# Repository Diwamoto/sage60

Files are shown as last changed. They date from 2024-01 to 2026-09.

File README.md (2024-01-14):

# Sage60

東プレスイッチを使った60%分割キーボードです。
nrf52840を使って無線接続で左右間接続、PCとの接続を行います。
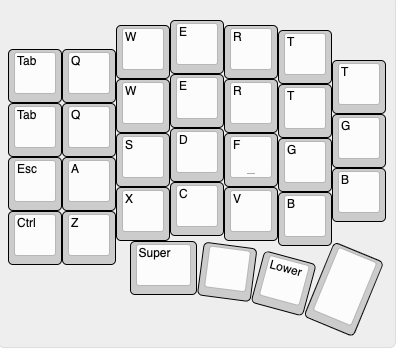
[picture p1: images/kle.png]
keyboard image


# ファームウェア

zmkを使用しています。
nrf52840にzmkを焼いて、adcを用いることで静電容量を読み取りキー入力を判定しています。
詳細な判定方法は[こちら](https://nogikes.booth.pm/items/2373281)や[こちら](https://booth.pm/ja/items/2232932)を参考にしてください。

# プロジェクトロードマップ

* 👍 左右間の無線通信
* 👍 PCとのBLE接続
* 👍 キーマップ変更
* 👍 Lipoバッテリーの充電
* ❌ BOMファイル等の準備によるPCBAまでサポート
* ❌ ラピッドトリガー機能
* ❌ Remap等のダイナミックキーマップ変更
* ❌ アルミケース
* ❌ ガスケットマウント

# 参考
* zmkの設定: [tako-config](https://github.com/ssbb/tako-config)
* 基板: [tako](https://github.com/ssbb/tako)

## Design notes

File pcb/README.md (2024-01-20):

# pcb 

## main

メインの静電容量を読み取るための基板。未検証。
pocで動作したら検証を行う。

## poc

ae_nrf52840を使って静電容量が検知できるかどうかを検証する。
100x100に入れてpcbaの費用以外を安くする。

## mx

同じ配列でmx用の基板
配列が果たして使いやすいのかを検証する。

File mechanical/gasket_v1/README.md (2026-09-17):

# SAGE60 gasket plate v1

This revision derives the plate geometry from the current boards:

- `pcb/mx_main/mx.kicad_pcb` — left, 30 Choc/MX switch cutouts
- `pcb/mx_right_tb/mx_right.kicad_pcb` — right, 28 Choc/MX switch cutouts and trackball area

The plate is intended as a 1.5 mm FR4 or similar laser/CNC-cut part. There is no copper, no electrical net, and no component data in the generated plate boards. The square switch openings are 14 mm with R0.25 corners and retain each source switch's position and rotation. The current switch footprints do not contain a manufacturing plate cutout, so this v1 keeps the 14 x 14 mm cutout convention from the existing `mx_plate` / `SW_Hole` design; confirm the actual switch body before ordering a batch.

## Files

The production-facing files are:

- `../../pcb/mx_plate/gasket_v1/mx_plate_gasket.dxf`
- `../../pcb/mx_plate_right_tb/gasket_v1/mx_plate_right_tb_gasket.dxf`
- `../../pcb/mx_plate/gasket_v1/mx_plate_gasket.step`
- `../../pcb/mx_plate_right_tb/gasket_v1/mx_plate_right_tb_gasket.step`

The `.kicad_pcb` files are useful for opening the geometry in KiCad and checking the switch holes. The `_case_reference.dxf` files include the plate outline, current PCB outline, gasket contacts, and switch cutouts on separate layers for case design.

## Case interface

The left half has six external gasket ears and the right trackball half has five; R5 is intentionally omitted on the right. Each ear has a 14 x 3 mm contact face; use two contacts per ear, one above and one below the plate. The initial case model uses:

- 1.5 mm plate thickness
- 1.5 mm gasket thickness before compression
- 20% initial compression, giving 1.2 mm per gasket
- 3.9 mm between the upper and lower case contact faces
- 0.5 mm lateral clearance between the plate and case pocket
- at least 0.5 mm free movement before the plate touches the case wall

The exact ear centers, tangent directions, and CAD coordinates are in `case_interface.json` and `gasket_positions.csv`. CAD coordinates use X right and Y up; PCB coordinates use X right and Y down.

Keep the right trackball holder, sensor board, and cable supported from the case. The plate intentionally leaves the trackball/cable area open so the ball assembly does not become a moving load on the switch plate.

## Regeneration and checks

Run `extract_boards.py` with KiCad's Python when the source PCB changes, then run `generate.py`. The generator stops if the source switch count, outline continuity, hole clearance, connectivity, or gasket-ear placement fails.

`verify_saved.py` reopens the generated KiCad boards, checks the DXF contours and rotated holes, and verifies that the exported STL is watertight. KiCad's STL preview uses its default stackup surface and reports approximately 1.43 mm for a 1.50 mm board body; the authoritative manufacturing thickness is the 1.50 mm value in the PCB/DXF design.

The latest checks are recorded in `validation.json`, `saved_cad_validation.json`, `drc_left.json`, and `drc_right.json`.

## If the plate is 3D printed

Do not simply change the whole plate from 1.5 mm to 5.0 mm. The current footprint is named `CherryMX_Choc_Hotswap_v2`; a flat 5 mm switch rim can prevent the switch retention features from engaging and can move the PCB 3.5 mm farther from the switch. Use a 5 mm structural frame with an underside relief around each switch so the local switch rim remains about 1.5–1.6 mm thick, or make the frame clear the switches and let the PCB retain them.

With 5 mm ears and two 1.5 mm gaskets compressed to 1.2 mm each, the case contact-face separation becomes 7.4 mm. The 3.9 mm value above applies only to the 1.5 mm plate version.

## Fusion case prototype

Fusion 360 was used to create optional, non-saved split-case fit-check bodies from the plate references. The plate interface itself has six raised supports on the left and five on the right; R5 is intentionally omitted on the right. The right half adds a 37 mm trackball opening from the current PMW3610 connector center and a 42 mm support lip. These case prototypes are not required for the plate handoff.

- `sage60_left_case_bottom.step` / `.stl`
- `sage60_left_case_top.stl`
- `sage60_left_case_complete.step`
- `sage60_right_tb_case_bottom.step` / `.stl`
- `sage60_right_tb_case_top.stl`
- `sage60_right_tb_case_complete.step`

The complete STEP files contain both case bodies for each half; the separate STL files are convenient for printing one body at a time. The rectangular shell is intentionally a first fit-check envelope. Keycap clearance, typing angle, battery pocket, antenna clearance, cable exits, and the final trackball holder should be set after the plate and holder are physically checked. The Fusion document was intentionally left unsaved; the exported files are the handoff artifacts.

### Contour-following case revision

The contour revision follows the generated plate exterior rather than the old rectangular bounding box. The case exterior is offset 2.0 mm outward from the plate, and the internal pocket is offset 0.5 mm outward to leave a small fit clearance; the resulting nominal wall is about 1.5 mm. The gasket ears and the right trackball-side outline are therefore retained in the case perimeter.

- `sage60_left_case_contour_bottom.step` / `.stl`
- `sage60_left_case_contour_top.stl`
- `sage60_left_case_contour_complete.step`
- `sage60_right_tb_case_contour_bottom.step` / `.stl`
- `sage60_right_tb_case_contour_top.stl`
- `sage60_right_tb_case_contour_complete.step`

### V2 magnetic two-piece case

The current case revision is a two-piece construction. The lower case carries the floor, the plate pocket, the gasket supports, and the trackball opening. The upper case is a single combined frame and skirt; its skirt starts below the lower-case top and covers the lower wall. The upper outline is a simplified convex polygon derived from the plate envelope, with 1.5 mm outline simplification tolerance and mostly straight edges. This follows the Altair-X direction of combining geometric arcs and bold straight edges while keeping the outside silhouette simple: <https://ai03.com/projects/altair/>.

- Lower outer offset from the simplified envelope: 2.8 mm
- Upper outer offset: 4.2 mm
- Upper skirt inner offset: 3.1 mm
- Plate opening clearance: 0.5 mm
- Lower case height / floor: 8.0 mm / 2.5 mm
- Upper skirt: Z 6.4–8.1 mm
- Upper frame: Z 7.9–11.6 mm
- Four blind magnet holes per half in each piece: nominal Ø3.4 mm × 2.2 mm deep, for Ø3 mm × 2 mm neodymium magnets

- `sage60_left_case_v2_bottom.step` / `.stl`
- `sage60_left_case_v2_top.stl`
- `sage60_left_case_v2_complete.step`
- `sage60_right_tb_case_v2_bottom.step` / `.stl`
- `sage60_right_tb_case_v2_top.stl`
- `sage60_right_tb_case_v2_complete.step`

The complete STEP files contain exactly two named bodies per half: `*_LOWER_CASE` and `*_UPPER_CASE`. The bottom and top STL files are exported from those combined bodies, including gasket supports and the right trackball lip.

### V3 controller-clearance revision

The V2 envelope filled the controller edge that is intentionally open in the
plate. V3 adds a simple rectangular service bay from the actual PCB
coordinates: the left XIAO nRF52840 is at the right edge and the right XIAO
nRF52840 Plus is at the left edge. The bay also covers the nearby battery JST
footprint. The lower case opens this unused controller edge through its full
height, while the upper case has a through-window from the skirt datum to the
top face. The opening runs to the corresponding outside edge so the module and
cable are not trapped behind the simplified convex silhouette.

- Left service bay (PCB coordinates): X 167.5–202.0 mm, Y 22.0–61.0 mm
- Right service bay (PCB coordinates): X 43.5–78.5 mm, Y 25.0–61.0 mm
- Upper window: Z 6.4–11.6 mm
- Lower controller bay: Z 0–8.0 mm

- `sage60_left_case_v3_bottom.step` / `.stl`
- `sage60_left_case_v3_top.stl`
- `sage60_left_case_v3_complete.step`
- `sage60_right_tb_case_v3_bottom.step` / `.stl`
- `sage60_right_tb_case_v3_top.stl`
- `sage60_right_tb_case_v3_complete.step`

The Fusion documents for this revision contain only the two case bodies per
half and include `*_LOWER_CONTROL_BAY_CUT` and `*_UPPER_CONTROL_WINDOW_CUT`
features. The controller keepout still needs a final physical check against
the exact XIAO board variant, USB plug, and battery cable bend radius.

## Mounting direction

For this prototype, gasket support at the plate perimeter is a good way to learn how the split halves feel independently. Keep the PCB floating or use soft PCB supports so the plate remains the primary load path. A tray or top mount is easier to tune, but it is stiffer and transfers more case vibration into the board.

For a future electro-capacitive version, bottom-mount is not a requirement. EC designs need the slider/dome/PCB spacing to remain controlled; the practical requirement is a rigid, repeatable plate-to-PCB assembly. A plate-plus-PCB sandwich can still be gasket-mounted by the plate, while the bottom case supports only the assembly and battery. If the future EC design uses an integrated plate, keep the gasket ears and case contact datum independent of the switch mechanism so the EC stack can be swapped without redesigning the case.

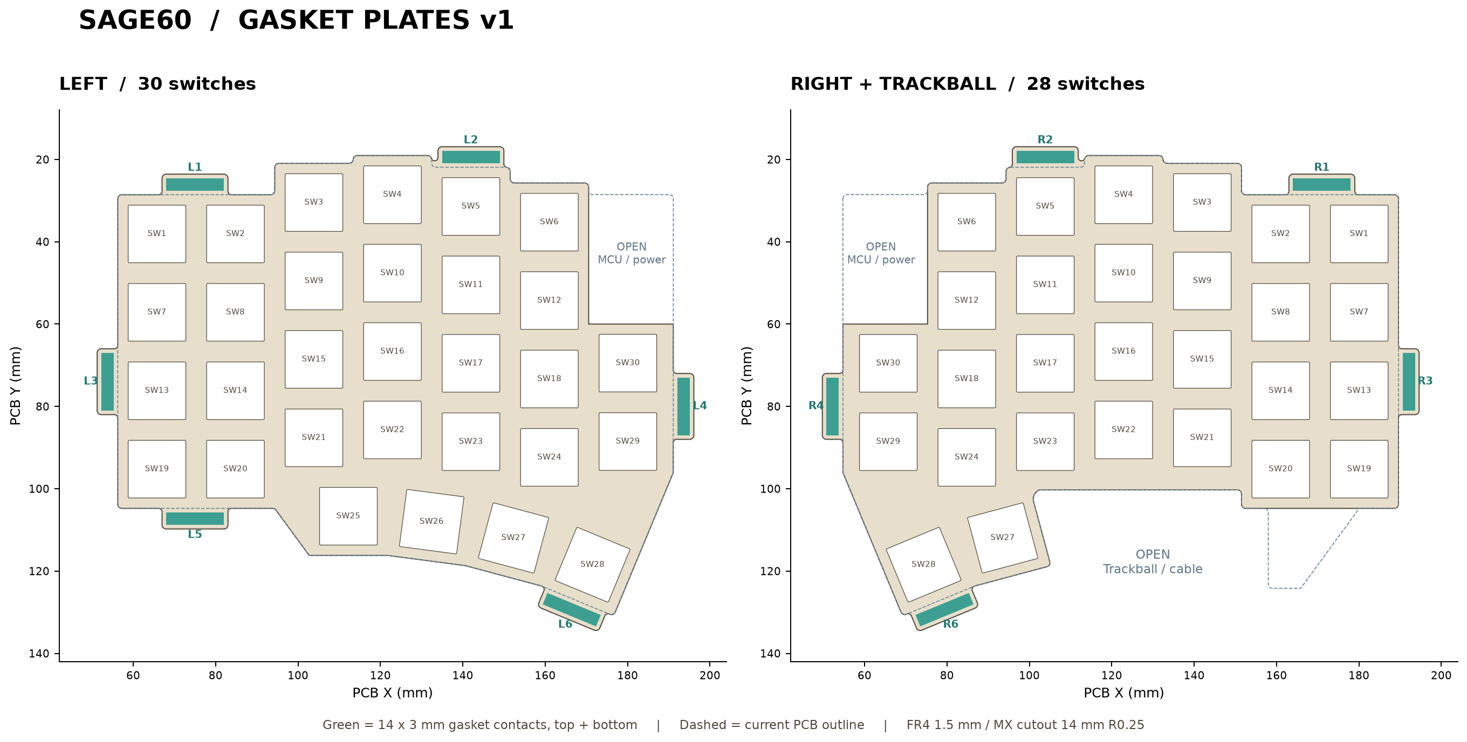
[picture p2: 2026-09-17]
mechanical/gasket_v1/plate_overview.png

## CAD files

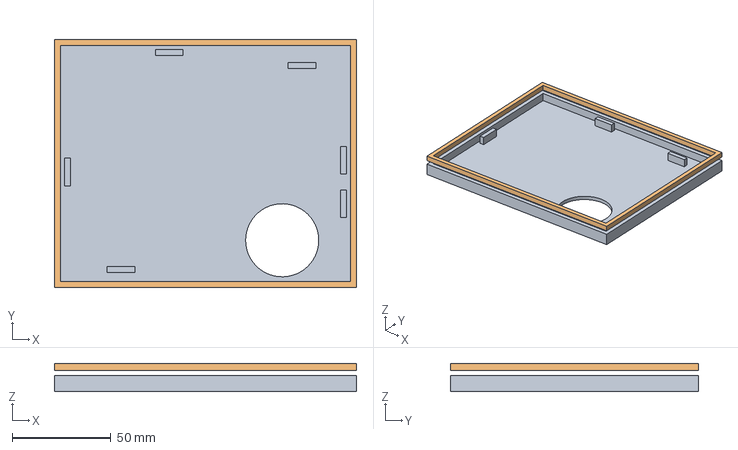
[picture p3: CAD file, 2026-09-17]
mechanical/gasket_v1/sage60_right_tb_case_complete.step
152.9 x 125.6 x 14.2 mm

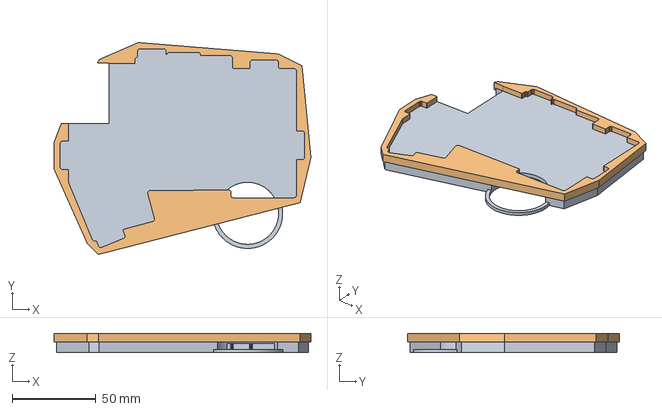
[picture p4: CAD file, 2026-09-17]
mechanical/gasket_v1/sage60_right_tb_case_v3_complete.step
153.3 x 126.4 x 11.6 mm

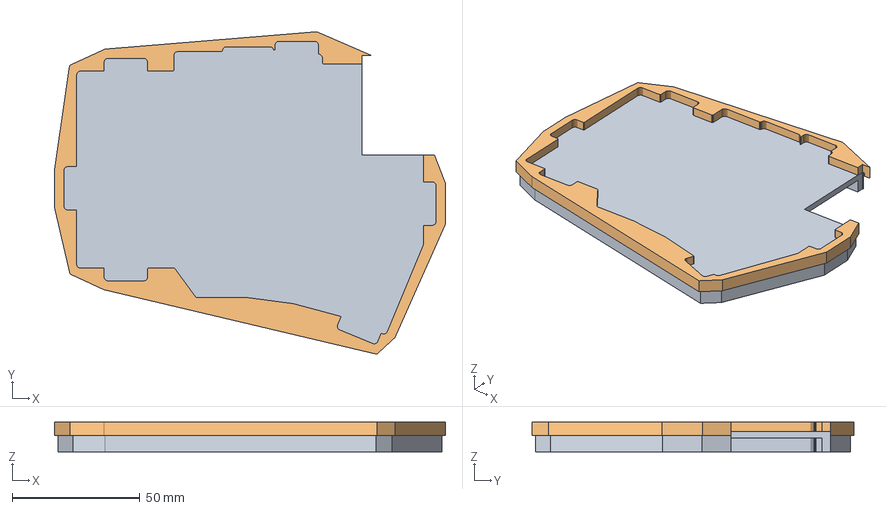
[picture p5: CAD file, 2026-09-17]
mechanical/gasket_v1/sage60_left_case_v3_complete.step
153.2 x 126.4 x 11.6 mm

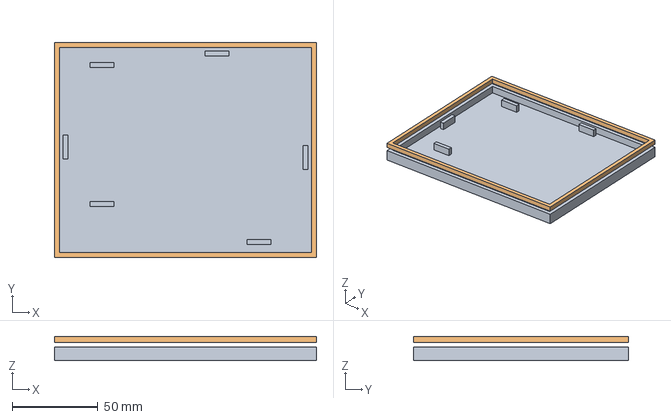
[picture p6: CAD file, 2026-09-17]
mechanical/gasket_v1/sage60_left_case_complete.step
152.9 x 125.6 x 14.2 mm

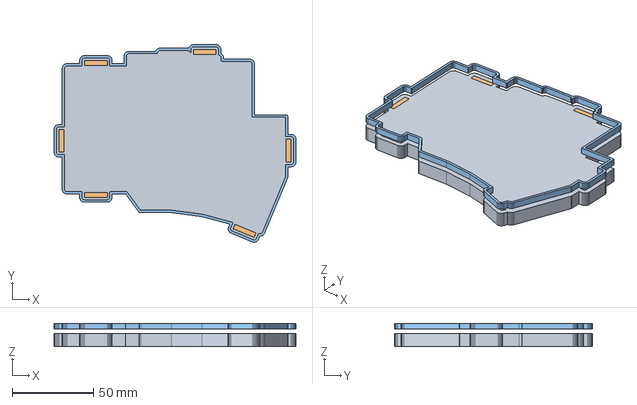
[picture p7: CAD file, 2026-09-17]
mechanical/gasket_v1/sage60_left_case_contour_complete.step
148.8 x 121.5 x 14.2 mm

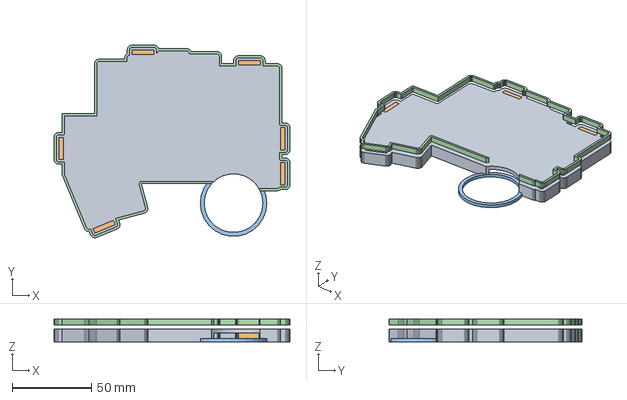
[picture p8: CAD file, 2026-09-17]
mechanical/gasket_v1/sage60_right_tb_case_contour_complete.step
148.8 x 121.5 x 14.2 mm

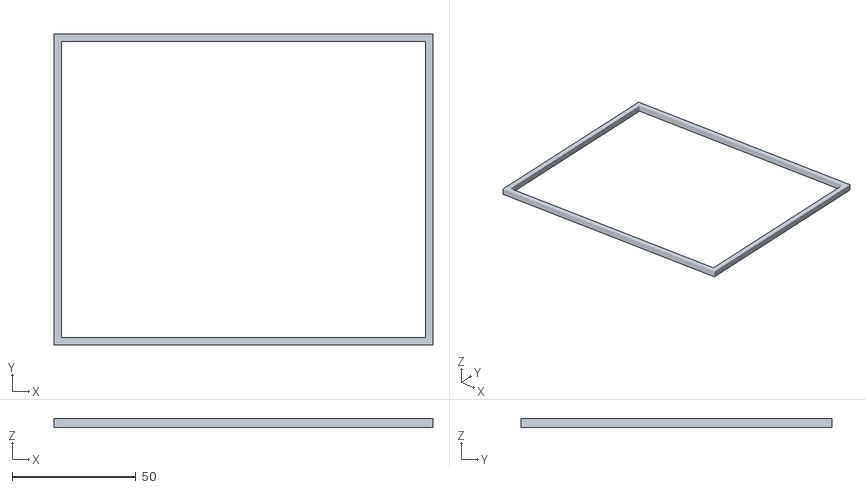
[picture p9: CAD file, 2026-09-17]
mechanical/gasket_v1/sage60_left_case_top.stl
152.9 x 125.6 x 3.50

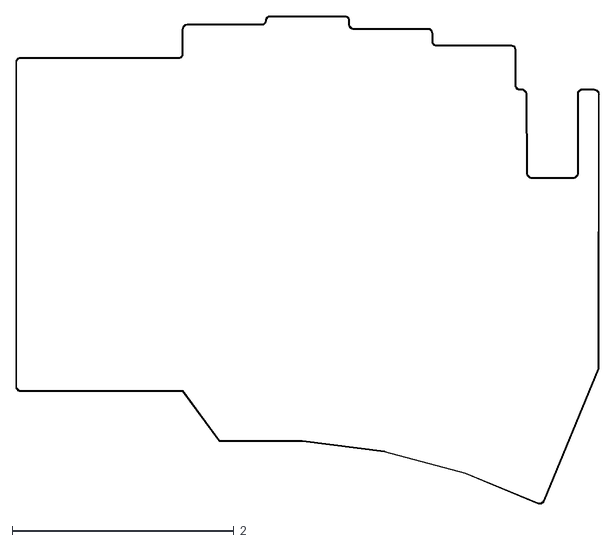
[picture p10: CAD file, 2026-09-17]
pcb/mx_main/mx-Edge_Cuts.dxf
5.25 x 4.39

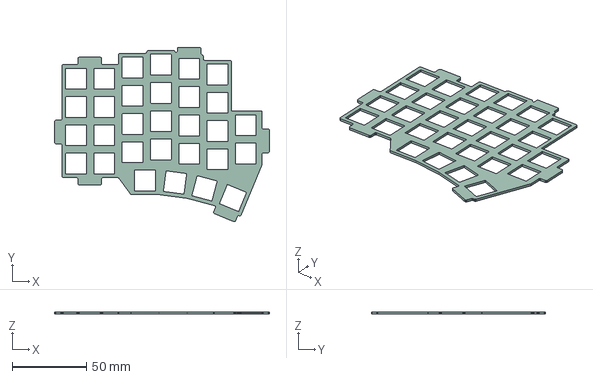
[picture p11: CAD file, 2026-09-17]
pcb/mx_plate/gasket_v1/mx_plate_gasket.step
144.8 x 117.5 x 1.43 mm

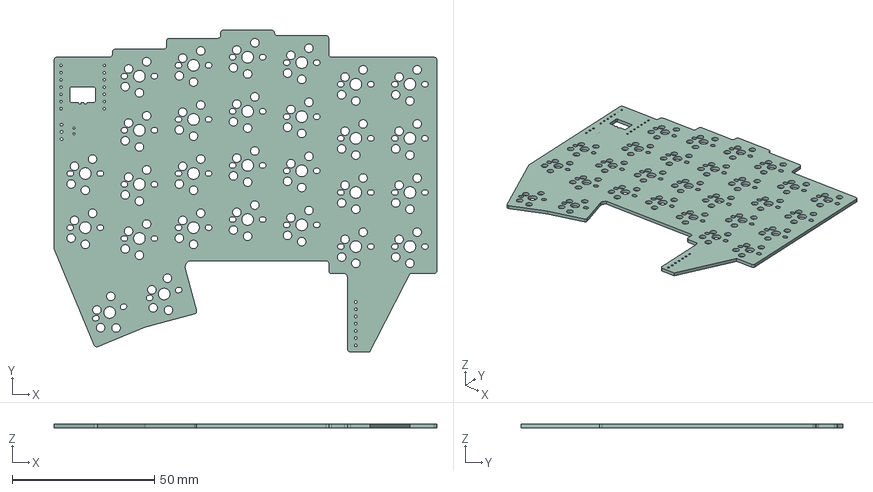
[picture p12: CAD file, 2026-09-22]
pcb/mx_right_tb/mx_right_tb.step
134.9 x 113.3 x 1.51 mm

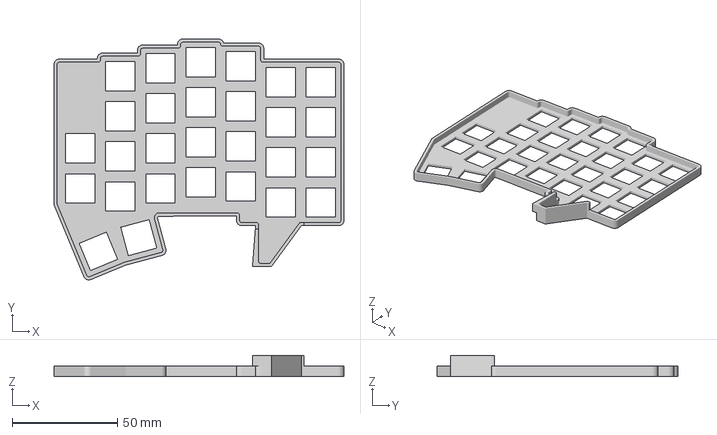
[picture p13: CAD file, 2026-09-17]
ボディ8.3mf
137.9 x 114.5 x 10.0 mm

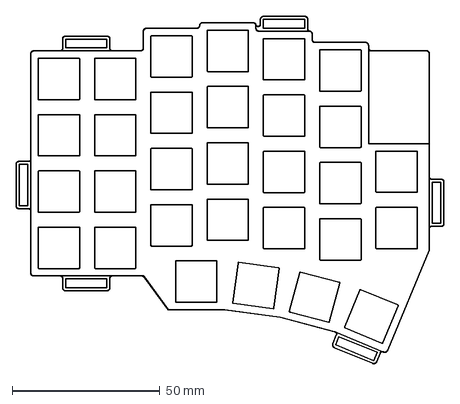
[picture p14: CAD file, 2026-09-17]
pcb/mx_plate/gasket_v1/mx_plate_gasket_case_reference.dxf
144.8 x 117.5 mm

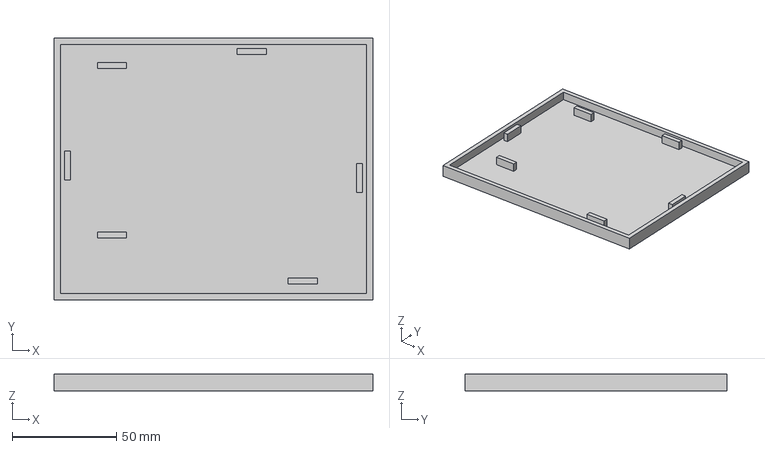
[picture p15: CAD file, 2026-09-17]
mechanical/gasket_v1/sage60_left_case_bottom.step
152.9 x 125.6 x 8.00 mm

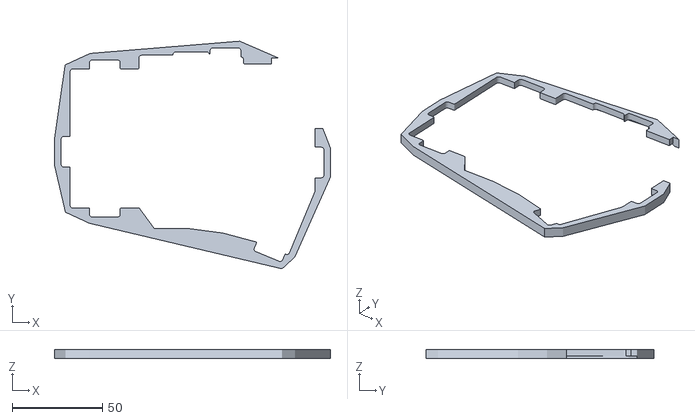
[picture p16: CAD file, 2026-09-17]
mechanical/gasket_v1/sage60_left_case_v3_top.stl
153.2 x 126.4 x 5.20

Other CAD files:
mechanical/gasket_v1/sage60_right_tb_case_top.stl
mechanical/gasket_v1/sage60_left_case_contour_top.stl
mechanical/gasket_v1/sage60_right_tb_case_bottom.step
mechanical/gasket_v1/sage60_right_tb_case_v3_top.stl
mechanical/gasket_v1/sage60_left_case_bottom.stl
mechanical/gasket_v1/sage60_left_case_contour_bottom.step
mechanical/gasket_v1/sage60_left_case_contour_bottom.stl
mechanical/gasket_v1/sage60_left_case_v2_bottom.step
mechanical/gasket_v1/sage60_left_case_v2_bottom.stl
mechanical/gasket_v1/sage60_left_case_v2_complete.step
mechanical/gasket_v1/sage60_left_case_v2_top.stl
mechanical/gasket_v1/sage60_left_case_v3_bottom.step
mechanical/gasket_v1/sage60_left_case_v3_bottom.stl
mechanical/gasket_v1/sage60_right_tb_case_bottom.stl
mechanical/gasket_v1/sage60_right_tb_case_contour_bottom.step
mechanical/gasket_v1/sage60_right_tb_case_contour_bottom.stl
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

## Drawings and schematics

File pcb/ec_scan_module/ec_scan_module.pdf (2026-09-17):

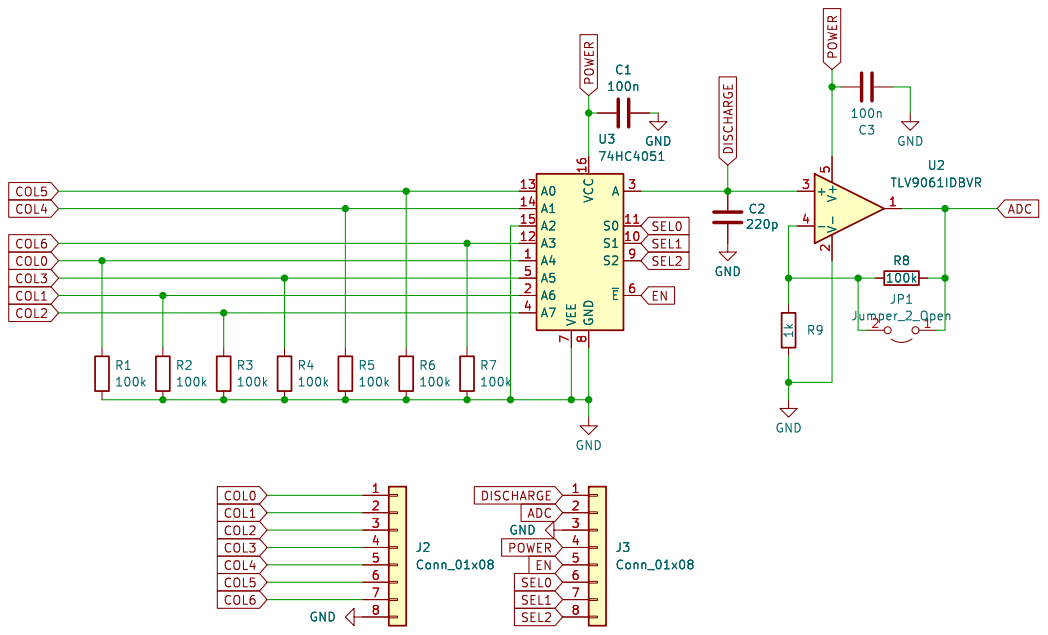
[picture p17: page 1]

Id: 1/1 Title: File: ec_scan_module.kicad_sch Sheet: /

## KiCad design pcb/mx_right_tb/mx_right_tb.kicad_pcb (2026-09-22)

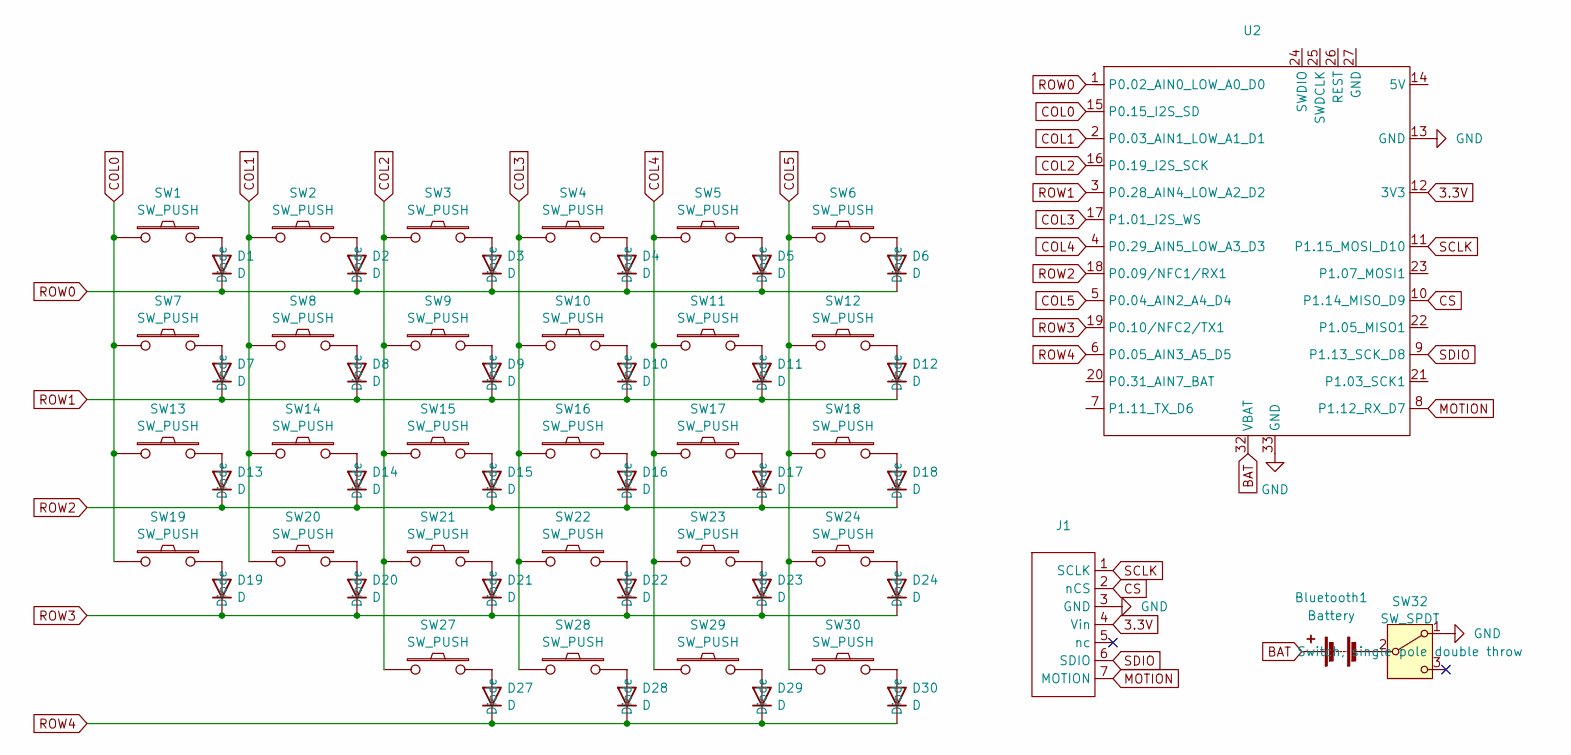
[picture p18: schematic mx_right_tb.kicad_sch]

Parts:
Bluetooth1: Battery
D1, D2, D3, D4, D5, D6, D7, D8, D9, D10, D11, D12, D13, D14, D15, D16, D17, D18, D19, D20, D21, D22, D23, D24, D27, D28, D29, D30: D; D3_SMD_v2
J1: pmw3610_connector
SW1, SW2, SW3, SW4, SW5, SW6, SW7, SW8, SW9, SW10, SW11, SW12, SW13, SW14, SW15, SW16, SW17, SW18, SW19, SW20, SW21, SW22, SW23, SW24, SW27, SW28, SW29, SW30: SW_PUSH; CherryMX_Choc_Hotswap_v2
SW32: SW_SPDT; PinHeader_1x03_P2.54mm_Vertical
U2: XIAO-nRF52840-Plus-DIP

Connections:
3.3V: J1.4 (Vin), U2.12 (3V3)
BAT: Bluetooth1.1 (+), U2.32 (VBAT)
COL0: SW1.1, SW7.1, SW13.1, SW19.1, U2.15 (P0.15_I2S_SD)
COL1: SW2.1, SW8.1, SW14.1, SW20.1, U2.2 (P0.03_AIN1_LOW_A1_D1)
COL2: SW3.1, SW9.1, SW15.1, SW21.1, SW27.1, U2.16 (P0.19_I2S_SCK)
COL3: SW4.1, SW10.1, SW16.1, SW22.1, SW28.1, U2.17 (P1.01_I2S_WS)
COL4: SW5.1, SW11.1, SW17.1, SW23.1, SW29.1, U2.4 (P0.29_AIN5_LOW_A3_D3)
COL5: SW6.1, SW12.1, SW18.1, SW24.1, SW30.1, U2.5 (P0.04_AIN2_A4_D4)
CS: J1.2 (nCS), U2.10 (P1.14_MISO_D9)
GND: J1.3 (GND), SW32.1 (A), U2.13 (GND), U2.33 (GND)
MOTION: J1.7 (MOTION), U2.8 (P1.12_RX_D7)
unnamed: Bluetooth1.2 (-), SW32.2 (B)
unnamed: D1.2 (A), SW1.2
unnamed: D2.2 (A), SW2.2
unnamed: D3.2 (A), SW3.2
unnamed: D4.2 (A), SW4.2
unnamed: D5.2 (A), SW5.2
unnamed: D6.2 (A), SW6.2
unnamed: D7.2 (A), SW7.2
unnamed: D8.2 (A), SW8.2
unnamed: D9.2 (A), SW9.2
unnamed: D10.2 (A), SW10.2
unnamed: D11.2 (A), SW11.2
unnamed: D12.2 (A), SW12.2
unnamed: D13.2 (A), SW13.2
unnamed: D14.2 (A), SW14.2
unnamed: D15.2 (A), SW15.2
unnamed: D16.2 (A), SW16.2
unnamed: D17.2 (A), SW17.2
unnamed: D18.2 (A), SW18.2
unnamed: D19.2 (A), SW19.2
unnamed: D20.2 (A), SW20.2
unnamed: D21.2 (A), SW21.2
unnamed: D22.2 (A), SW22.2
unnamed: D23.2 (A), SW23.2
unnamed: D24.2 (A), SW24.2
unnamed: D27.2 (A), SW27.2
unnamed: D28.2 (A), SW28.2
unnamed: D29.2 (A), SW29.2
unnamed: D30.2 (A), SW30.2
ROW0: D1.1 (K), D2.1 (K), D3.1 (K), D4.1 (K), D5.1 (K), D6.1 (K), U2.1 (P0.02_AIN0_LOW_A0_D0)
ROW1: D7.1 (K), D8.1 (K), D9.1 (K), D10.1 (K), D11.1 (K), D12.1 (K), U2.3 (P0.28_AIN4_LOW_A2_D2)
ROW2: D13.1 (K), D14.1 (K), D15.1 (K), D16.1 (K), D17.1 (K), D18.1 (K), U2.18 (P0.09/NFC1/RX1)
ROW3: D19.1 (K), D20.1 (K), D21.1 (K), D22.1 (K), D23.1 (K), D24.1 (K), U2.19 (P0.10/NFC2/TX1)
ROW4: D27.1 (K), D28.1 (K), D29.1 (K), D30.1 (K), U2.6 (P0.05_AIN3_A5_D5)
SCLK: J1.1 (SCLK), U2.11 (P1.15_MOSI_D10)
SDIO: J1.6 (SDIO), U2.9 (P1.13_SCK_D8)

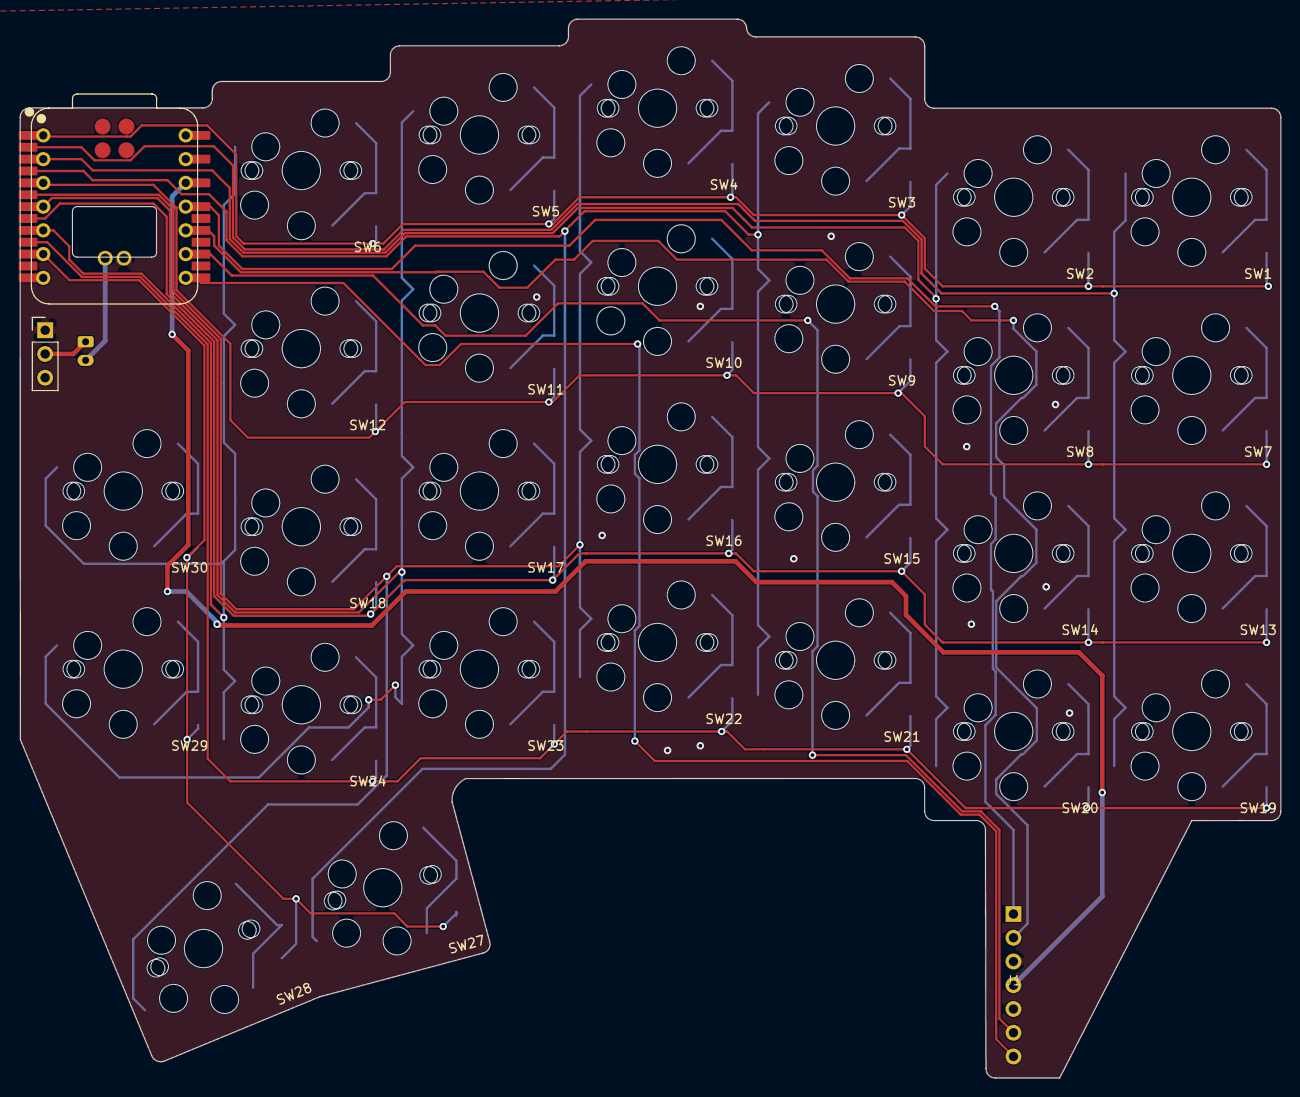
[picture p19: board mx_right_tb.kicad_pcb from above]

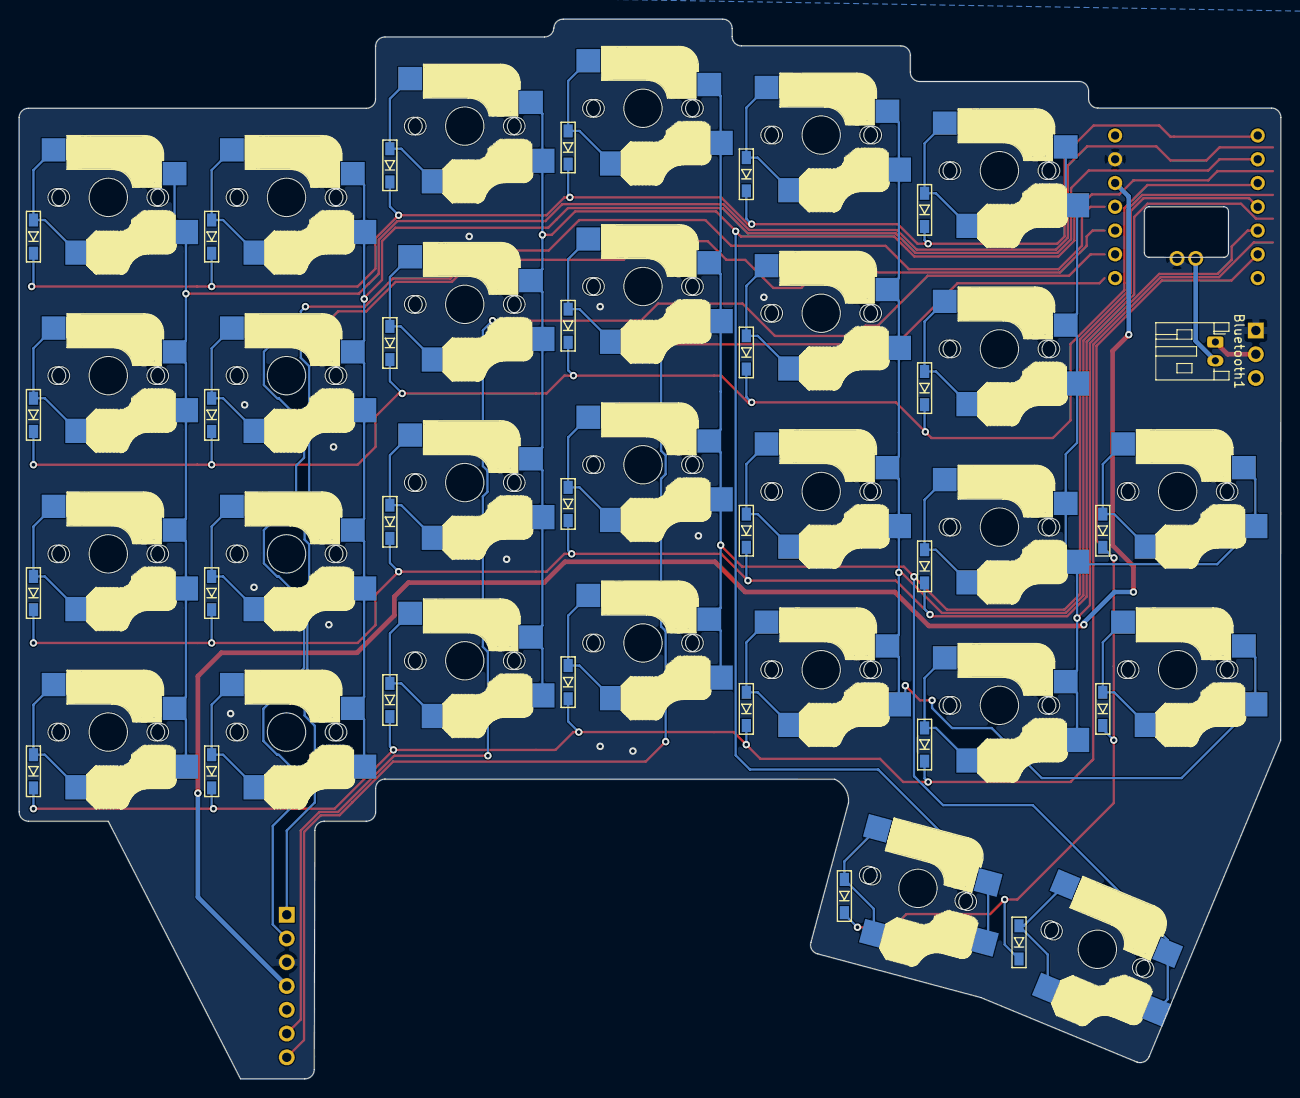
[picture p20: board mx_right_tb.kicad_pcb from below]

Board: 2 copper layers, 134.9 x 113.3 mm, 60 parts (29 on the bottom side), 47 nets.

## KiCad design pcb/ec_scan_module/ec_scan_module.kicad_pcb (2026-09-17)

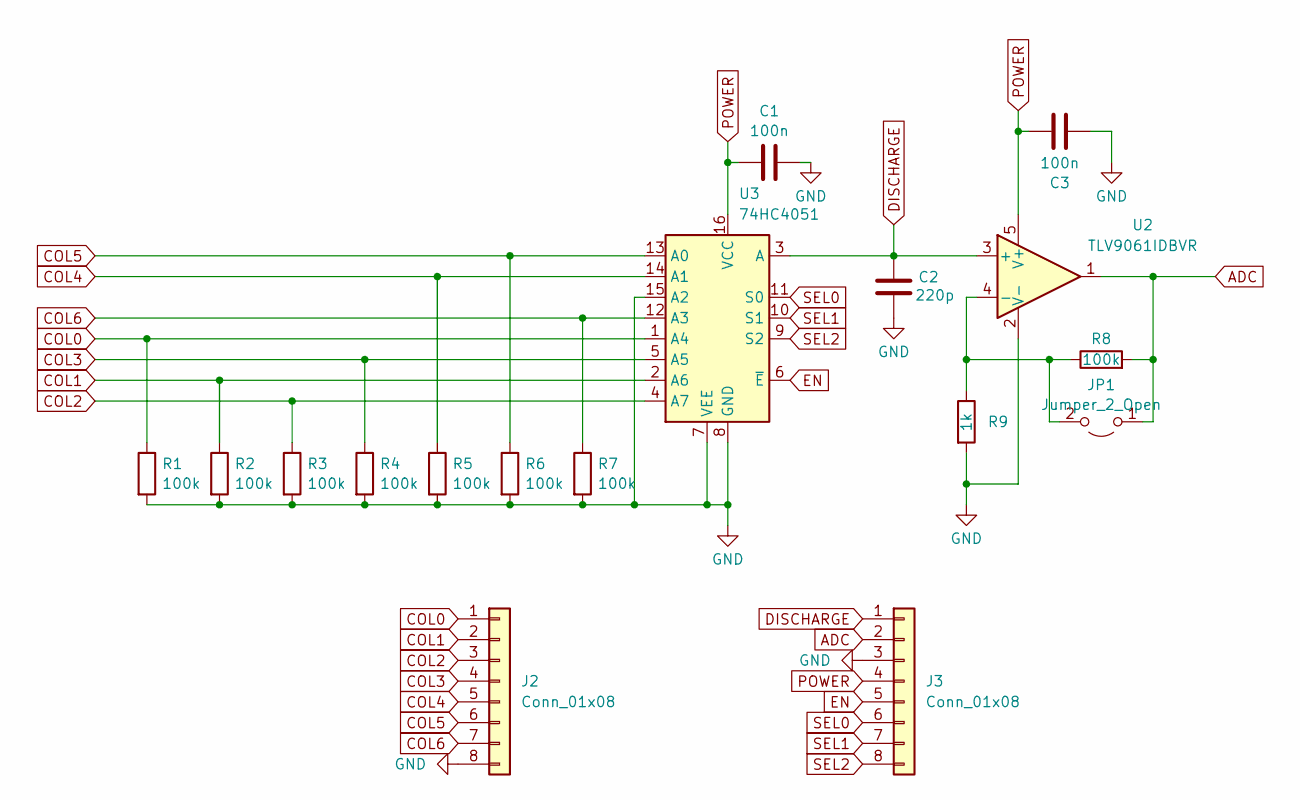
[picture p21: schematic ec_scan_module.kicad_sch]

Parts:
C1, C3: 100n; C_0402_1005Metric
C2: 220p; C_0402_1005Metric
J2, J3: Conn_01x08; PinHeader_1x08_P2.54mm_Vertical
JP1: Jumper_2_Open; R_0201_0603Metric_Pad0.64x0.40mm_HandSolder
R1, R2, R3, R4, R5, R6, R7, R8: 100k; R_0402_1005Metric
R9: 1k; R_0402_1005Metric
U2: TLV9061IDBVR; SOT-23-5
U3: 74HC4051; TSSOP-16_4.4x5mm_P0.65mm

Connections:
ADC: J3.2, JP1.1 (A), R8.2, U2.1
COL0: J2.1, R1.1, U3.1 (A4)
COL1: J2.2, R2.1, U3.2 (A6)
COL2: J2.3, R3.1, U3.4 (A7)
COL3: J2.4, R4.1, U3.5 (A5)
COL4: J2.5, R5.1, U3.14 (A1)
COL5: J2.6, R6.1, U3.13 (A0)
COL6: J2.7, R7.1, U3.12 (A3)
DISCHARGE: C2.2, J3.1, U2.3 (+), U3.3 (A)
EN: J3.5, U3.6 (~E)
GND: C1.2, C2.1, C3.1, J2.8, J3.3, R1.2, R2.2, R3.2, R4.2, R5.2, R6.2, R7.2, R9.2, U2.2 (V-), U3.7 (VEE), U3.8 (GND), U3.15 (A2)
unnamed: JP1.2 (B), R8.1, R9.1, U2.4 (-)
POWER: C1.1, C3.2, J3.4, U2.5 (V+), U3.16 (VCC)
SEL0: J3.6, U3.11 (S0)
SEL1: J3.7, U3.10 (S1)
SEL2: J3.8, U3.9 (S2)

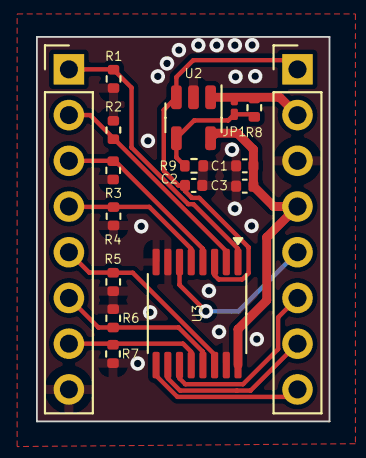
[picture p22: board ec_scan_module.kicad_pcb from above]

Board: 2 copper layers, 16.3 x 21.4 mm, 17 parts (0 on the bottom side), 16 nets.

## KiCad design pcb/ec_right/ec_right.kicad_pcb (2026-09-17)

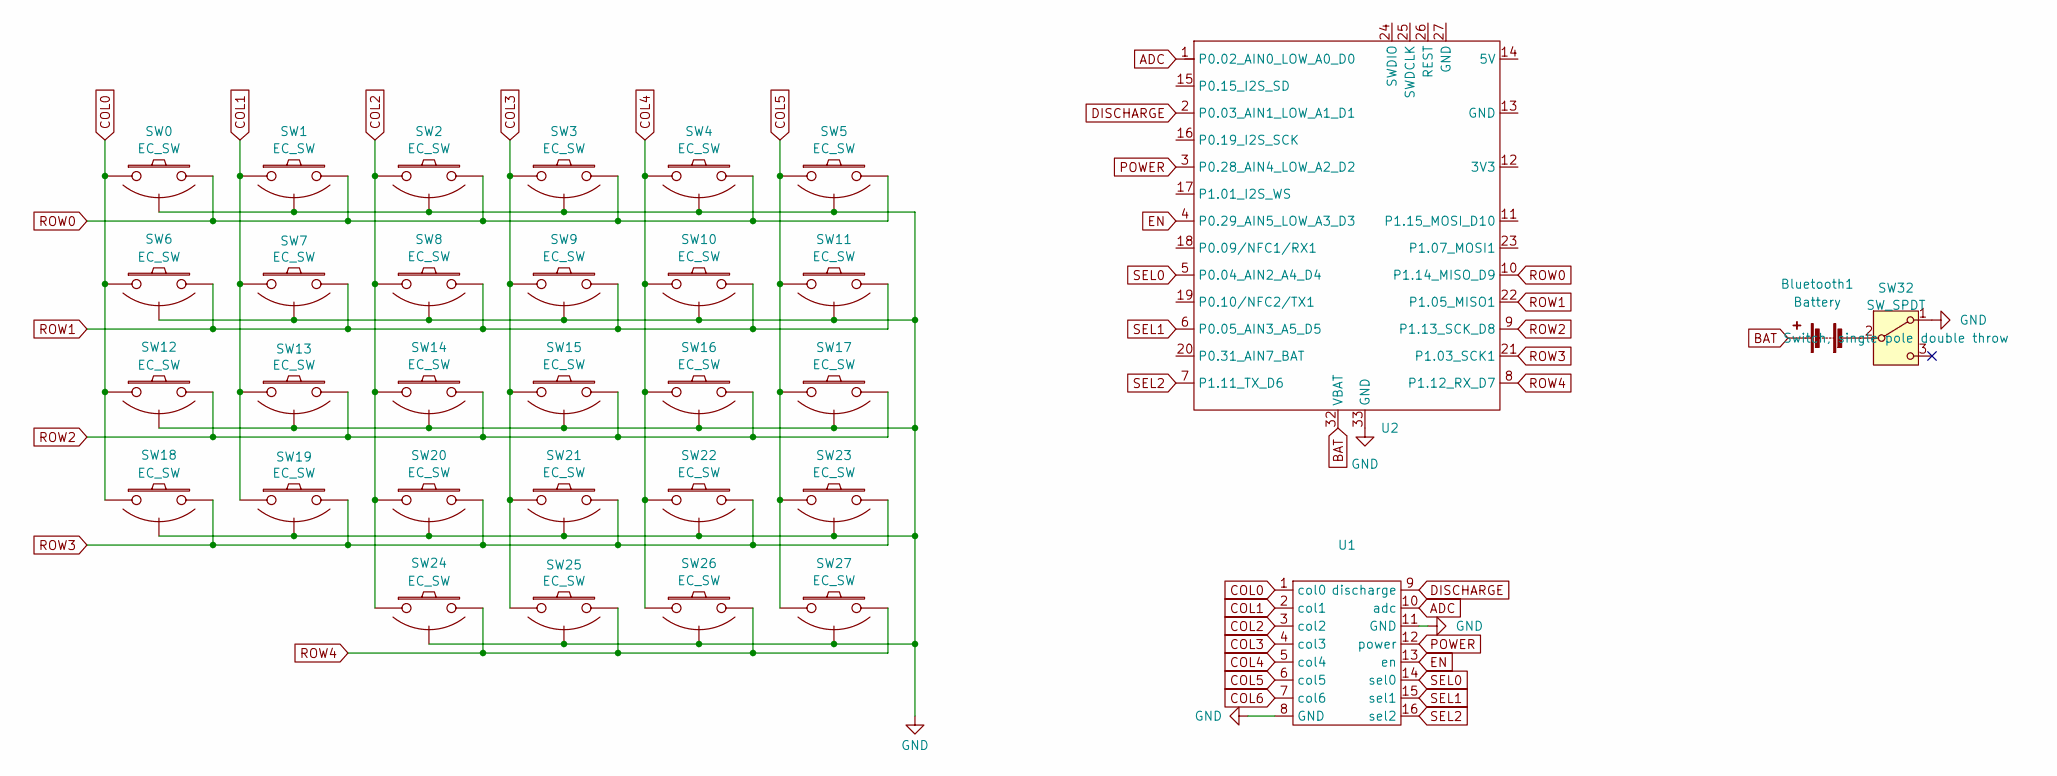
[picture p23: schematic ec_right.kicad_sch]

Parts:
Bluetooth1: Battery
SW0, SW1, SW2, SW3, SW4, SW5, SW6, SW7, SW8, SW9, SW10, SW11, SW12, SW13, SW14, SW15, SW16, SW17, SW18, SW19, SW20, SW21, SW22, SW23, SW24, SW25, SW26, SW27: EC_SW; ecs_pad_1U_no_ring
SW32: SW_SPDT; PinHeader_1x03_P2.54mm_Vertical
U1: ec_scan_module
U2: XIAO-nRF52840-Plus-DIP

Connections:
ADC: U1.10 (adc), U2.1 (P0.02_AIN0_LOW_A0_D0)
BAT: Bluetooth1.1 (+), U2.32 (VBAT)
COL0: SW0.1, SW6.1, SW12.1, SW18.1, U1.1 (col0)
COL1: SW1.1, SW7.1, SW13.1, SW19.1, U1.2 (col1)
COL2: SW2.1, SW8.1, SW14.1, SW20.1, SW24.1, U1.3 (col2)
COL3: SW3.1, SW9.1, SW15.1, SW21.1, SW25.1, U1.4 (col3)
COL4: SW4.1, SW10.1, SW16.1, SW22.1, SW26.1, U1.5 (col4)
COL5: SW5.1, SW11.1, SW17.1, SW23.1, SW27.1, U1.6 (col5)
COL6: U1.7 (col6)
DISCHARGE: U1.9 (discharge), U2.2 (P0.03_AIN1_LOW_A1_D1)
EN: U1.13 (en), U2.4 (P0.29_AIN5_LOW_A3_D3)
GND: SW0.3 (SG), SW1.3 (SG), SW2.3 (SG), SW3.3 (SG), SW4.3 (SG), SW5.3 (SG), SW6.3 (SG), SW7.3 (SG), SW8.3 (SG), SW9.3 (SG), SW10.3 (SG), SW11.3 (SG), SW12.3 (SG), SW13.3 (SG), SW14.3 (SG), SW15.3 (SG), SW16.3 (SG), SW17.3 (SG), SW18.3 (SG), SW19.3 (SG), SW20.3 (SG), SW21.3 (SG), SW22.3 (SG), SW23.3 (SG), SW24.3 (SG), SW25.3 (SG), SW26.3 (SG), SW27.3 (SG), SW32.1 (A), U1.8 (GND), U1.11 (GND), U2.33 (GND)
unnamed: Bluetooth1.2 (-), SW32.2 (B)
POWER: U1.12 (power), U2.3 (P0.28_AIN4_LOW_A2_D2)
ROW0: SW0.2, SW1.2, SW2.2, SW3.2, SW4.2, SW5.2, U2.10 (P1.14_MISO_D9)
ROW1: SW6.2, SW7.2, SW8.2, SW9.2, SW10.2, SW11.2, U2.22 (P1.05_MISO1)
ROW2: SW12.2, SW13.2, SW14.2, SW15.2, SW16.2, SW17.2, U2.9 (P1.13_SCK_D8)
ROW3: SW18.2, SW19.2, SW20.2, SW21.2, SW22.2, SW23.2, U2.21 (P1.03_SCK1)
ROW4: SW24.2, SW25.2, SW26.2, SW27.2, U2.8 (P1.12_RX_D7)
SEL0: U1.14 (sel0), U2.5 (P0.04_AIN2_A4_D4)
SEL1: U1.15 (sel1), U2.6 (P0.05_AIN3_A5_D5)
SEL2: U1.16 (sel2), U2.7 (P1.11_TX_D6)

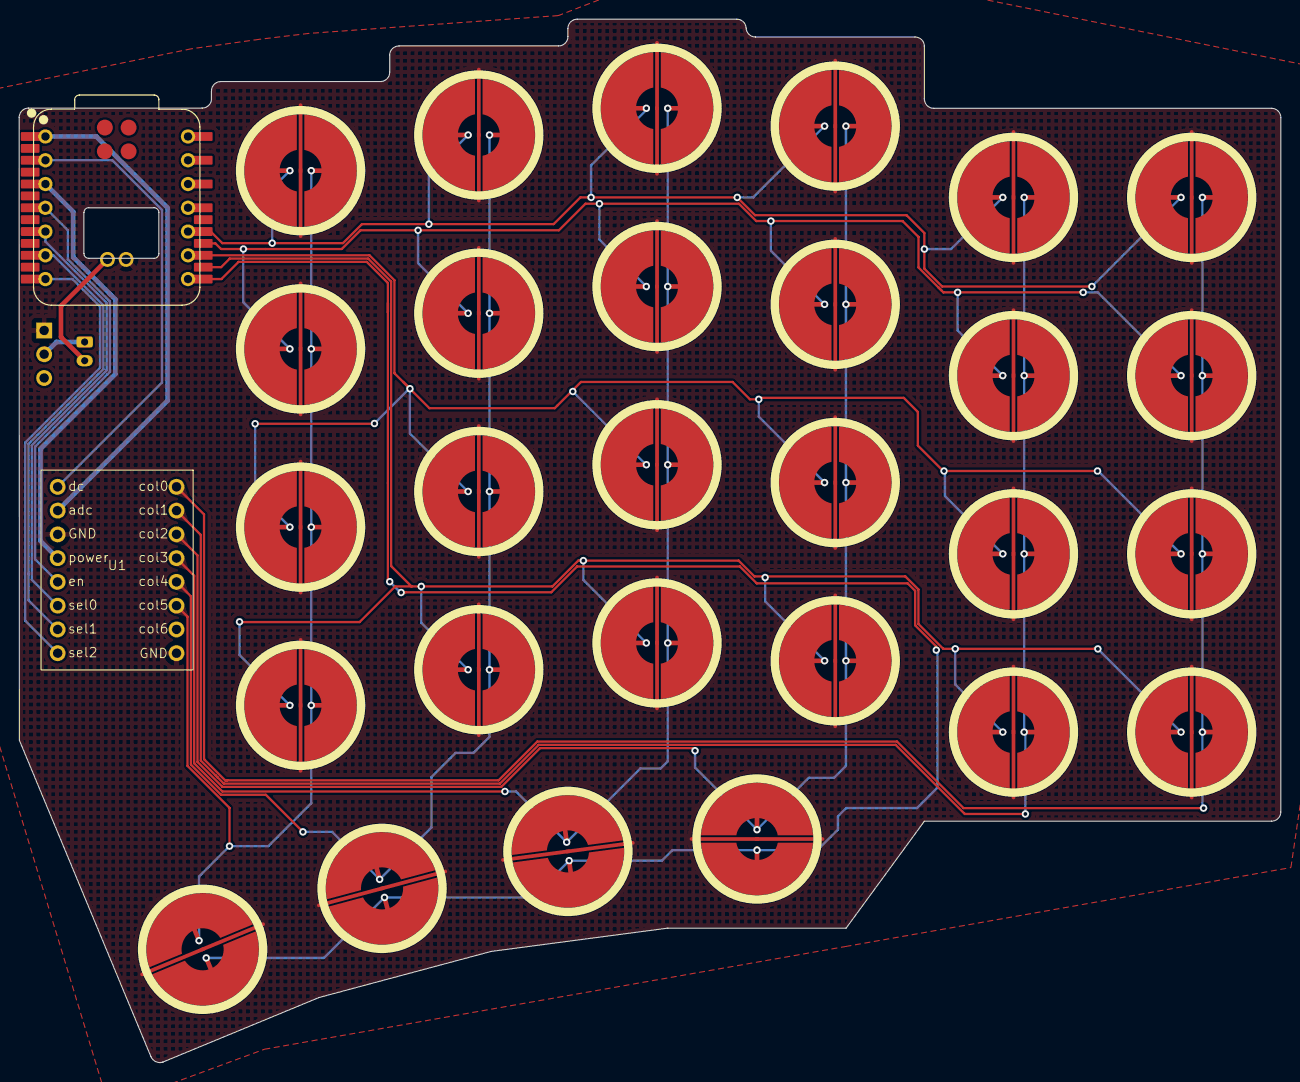
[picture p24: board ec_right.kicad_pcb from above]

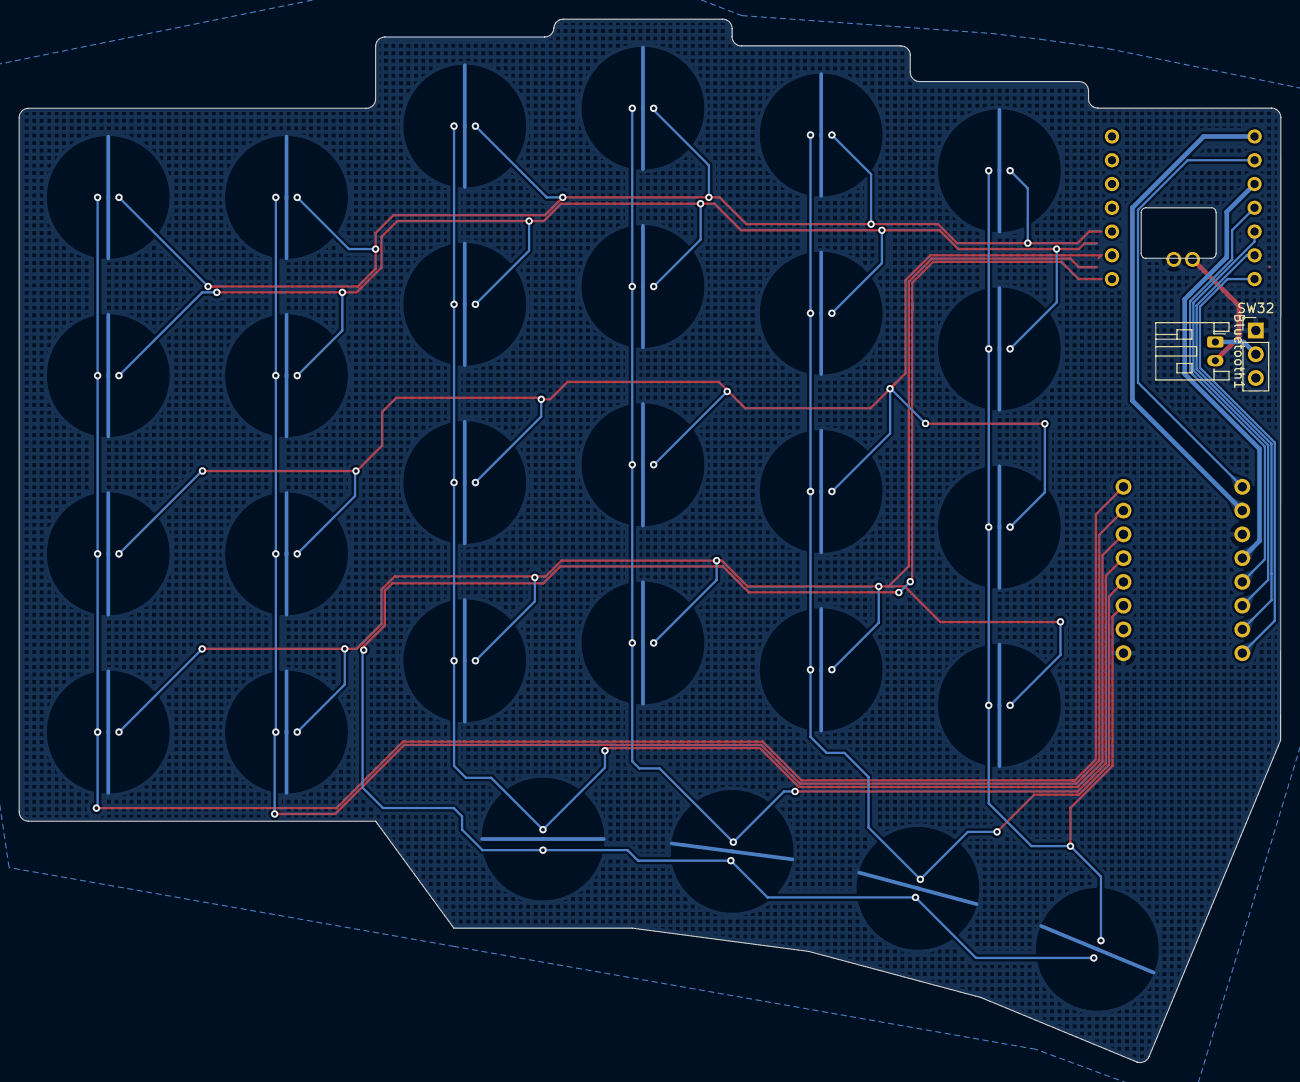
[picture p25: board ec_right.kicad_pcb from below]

Board: 2 copper layers, 134.9 x 111.5 mm, 32 parts (3 on the bottom side), 21 nets.

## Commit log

2024-01-14 Fix keyboard layout editorで読み込めるようにjsonを調整
2024-01-20 Add main
    [main.kicad_pcb, main.kicad_sch]
2024-01-20 Add poc
    [poc.kicad_pcb, poc.kicad_sch]
2024-01-23 Fix pocの設定を変更
2024-01-23 Add mx版の基板
    [mx.kicad_pcb, mx.kicad_sch]
2024-01-23 Add mxのdaughter
    [daughter.kicad_pcb, daughter.kicad_sch]
2024-01-23 Fix フォルダ変更
    [daughter.kicad_pcb, daughter.kicad_sch]
2024-01-23 Fix 穴の位置を微調整
    [mx.kicad_pcb]
2024-01-23 Add プレート
    [plate.kicad_pcb, plate.kicad_sch]
2024-01-25 Fix 微調整
    [plate.kicad_pcb, plate.kicad_sch]
2024-02-22 release: sage60 v0.0.1
    [daughter.kicad_pcb, daughter.kicad_sch, mx.kicad_pcb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]
2024-09-15 feat: add ec_saan_module
    [daughter.kicad_pcb, daughter.kicad_sch, ec_scan_module.kicad_pcb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]
2026-10-03 feat: sage60 case generator, phi6 magnets and shared plate
    - mechanical/case: scripts that build the split case (MX and low-profile) in Fusion from KiCad
    (outline, gasket shelf, USB-C, slide switch, MCU cover, trackball), with interference checks and
    PCB/switch/keycap reference models for renders
    - top case: case A (skirt down to the desk); guards over the gaps between the main block, the thumb
    cluster and the right column; the bare PCB around the trackball is covered too
    - magnets: Daiso phi6x3, 4 per side
    - left PCB: reroute ROW4 near SW28 and add a semicircular edge notch for a magnet post
    - plate: one plate for both halves; the right half snips off the trackball part (slots + bridg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
    [Kailh-CherryMX-Socket.step, XIAO-nRF52840 v15.step, cherry_mx.step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]
2026-10-03 chore: export the shared plate as one 3MF
2026-10-03 chore: also export the shared plate at 1.2 mm for Choc v2
2026-10-03 docs: Choc v2 plate is the shared plate at 1.2 mm
2026-10-03 fix: right PCB tongue clears the trackball leg; drop thin case strips around the trackball
    - right PCB: J1 tongue left edge x 158.0 -> 158.9 (trackball case leg arm overlapped 0.49 mm),
    SDIO / MOTION traces moved 0.32 right; DRC unchanged
    - right case: no top case between the trackball and row 4 (2-4 mm strips, hard to print);
    parts thinner than 3 mm (top) / 2 mm (bottom) near the trackball are cut; thumb rim 4 -> 5.5 mm
    [mx_right_tb.kicad_pcb]
2026-10-03 feat: enclose the trackball front on the right case; MX plate 1.2 mm
    - right case: in front of the ball centre the case surrounds the trackball case (front edge pushed
    out 5.5 mm, LP 6.6 mm; bottom wall >= 2, top case incl. skirt >= 3); behind it stays open
    - top ring opening may be two loops (keys, trackball); TB_ACCESS / TOP_RING_INNER take several loops
    - MX uses the 1.2 mm shared plate too: plate_t 1.2, pcb_gap 3.8 (PCB top stays at -5.0)
2026-10-03 feat: right case front as one straight edge from the thumb cluster to the pinky side
2026-10-04 feat: right case front trimmed to the thumb cluster and the trackball (convex hull)
2026-10-04 feat: right case front follows the thumb cluster and the trackball (least margin)
2026-10-05 feat: CNC-ready case geometry; lower the right top case frame in front of the trackball
    - JLCCNC rules: corner R from wall height, dog-bone reliefs on the cavity,
    open-top USB / switch slots, magnet walls 0.8, machinability.py checks
    (undercut / sharp / radius / holes / thin all 0 on the four documents)
    - Right top case: in front of the ball centre the frame round the trackball
    case is lowered by tb_front_drop (MX 7 mm to the plate top, LP 1 mm);
    TB_FRONT_LOW crosses the wall square to it
2026-10-06 feat: flat MX floor with a battery pocket, MCU cover (DXF), LP raised MCU block
    - MX: the cavity floor is flat at cav_z (thin foam under the sockets); only the
    battery + JST get a pocket, the rest is filled
    - MCU cover (plywood, walnut look) over the MCU wall and the outer wall top,
    exported as DXF (case/sage60_*_mcu_cover.dxf, mcu_cover_dxf.py); its inner
    edges keep 1 mm off the keycaps that overhang the MCU opening
    - LP: the MCU part is a raised block (mcu_cover_z 4.8) so the 2.5 mm cover
    clears the USB plug and needs no notch; OUTER_R 2.1 for its height
    - cover extrude started twice offset (floated 3.9 mm): fixed; check.py now
    checks the cover sits on the wall, check_parts.py in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
    [sage60_left_lp_mcu_cover.dxf, sage60_left_mcu_cover.dxf, sage60_right_lp_mcu_cover.dxf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]
2026-10-06 fix: right PCB tongue edge 1 mm away from the trackball sensor board
    tongue_trim.py: the J1 tongue's left edge x 158.9 -> 159.9; SDIO / MOTION
    rerouted right of J1 (MOTION via to B.Cu), two GND stitching vias; zones refilled.
    [mx_right_tb.kicad_pcb]
2026-10-06 feat: plate magnet notch fillets, 1.2 mm shared plate 3MF without kicad-cli
    - mx_plate / mx_right_tb_plate: magnet notch r5.15 + R1 root fillets
    (notch_fillet.py, applied earlier but left uncommitted)
    - plate_3mf.py: extrude the Edge.Cuts outline in Python (kicad-cli hung);
    one 1.2 mm plate for MX and Choc v2; asserts every loop is a hole
    - case/sage60_shared_plate.3mf
    [mx_plate.kicad_pcb, mx_right_tb_plate.kicad_pcb, sage60_shared_plate.3mf]
2026-10-06 feat: case 3MFs for test prints (bottom, top, cover; MX and LP) and their exporter
    [sage60_left_bottom.3mf, sage60_left_cover.3mf, sage60_left_lp_bottom.3mf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]
2026-10-07 fix: remove the top case wedge between the right thumb cluster and the trackball
    - make_right.py: TB_FRONT_LOW's left edge starts 3 mm right of the thumb
    cluster's front right corner (MX: down to z=0, LP: -1 mm); no sliver left
    - re-apply notch_fillet.py to both PCBs (r4.45 notch + R2 fillets had been lost)
    - right MX / LP specs, CNC reports (all 0) and test print 3MFs regenerated
    [mx.kicad_pcb, mx_right_tb.kicad_pcb, sage60_right_bottom.3mf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]
2026-10-07 docs: sage60-case skill notes the thumb / trackball wedge cut
2026-10-08 feat: ZMK firmware for MX (trackball) and EC under firmware/zmk
    - Latest ZMK (main, xiao_ble//zmk); CI builds from firmware/zmk via build-user-config inputs
    - MX: right half is mx_right_tb (XIAO Plus + PMW3610), trackball forwarded to the central via zmk,input-split
    - EC: sage60_ec shield on petejohanson/ec-support-zmk-module, pins from pcb/ec_main and pcb/ec_right, physical layout generated from PCB switch positions, calibrator images in the build matrix
2026-10-15 feat: order-ready MX boards (phi 5 centre holes), separate left / right plates, case updates
    - PCBs: switch centre holes phi 4.1 -> 5 for Kailh Choc v2 (centre_hole.py); the tracks that fell
    inside the new hole clearance are rerouted by centre_reroute.py (grid A*, vias where one layer is
    full). DRC errors unchanged, 0 unconnected, schematic parity as before.
    - SW32 stays a 3-pin THT footprint (2.54 mm); the case's knob opening follows its middle pin
    (SW_Y -54.86) and the finger scoop sits 1 mm toward +y to avoid a thin wall at the MCU block.
    - Plates: one per side (pcb/mx_left_plate, pcb/mx_right_tb_plate) instead of the shared
    breakaway plate; 1.2 mm 3MFs for test prints.
    - Top case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
2026-10-27 fix: MX transform, physical layout and keymap follow the real PCB key positions
    ROW4 is not a bottom row: COL4/COL5 are the inner-column keys and
    COL0-COL3 the thumb keys (right half: COL2/COL3 only). 58 keys, positions
    from the KiCad footprints. Drop the sage60_test_left bring-up shield.
2026-10-28 fix: MX matrix is col2row (cathode on ROW per the KiCad netlist)
2026-10-29 feat(case): magnets hold the trackball case; MCU cover magnet; J1 pin socket
    - trackball case: the two M1.7 screw bosses grow to r3.75 and take a
    phi6x3 magnet from below (tb_socket_cut.py); the bottom case gets
    facing phi6.1x3.1 holes in the seat (TB_MAGS / TB_MAG_CUT) instead of
    the through holes and desk-side counterbores
    - MCU cover held by one magnet in a top case boss + steel disc
    - J1: round-pin socket + cut-down L header (tongue_socket.py, stage6
    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
2026-10-30 chore: add production outputs, 7deg shims, mx_plate leftovers
    - production/cnc: case STEPs for the JLCCNC quote (export_step.py).
    The right bottom STEPs predate the trackball magnets (1ce5215);
    re-export before ordering
    - production/metal_plate: plate DXF/STEP
    - case/{left,right}_7deg_shim.stl
    - pcb/mx_plate (old name of mx_left_plate), mx.kicad_pro
2026-10-31 chore: reorganise the repository
    - pcb/: boards under pcb/mx/{left,right_tb,left_plate,right_tb_plate}
    and pcb/ec/{main,right,plate,scan_module}; only .kicad_pro/.kicad_pcb/
    .kicad_sch are tracked (backups, .kicad_prl, plugin settings,
    autorouter files and outputs stay local). Removed pcb/old, mx_right,
    mx_plate, the gasket_v1 plate and the mx_main snapshot
    - case/ (was mechanical/case): one-shot PCB/plate edits in case/oneshot/,
    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
2026-10-31 ci: drop Node 20 actions and add gerber export
    Remove the merge job and actions/cache from the ZMK build, and move
    checkout and upload-artifact to their Node 24 majors. Add a workflow that
    exports JLCPCB gerbers per board, documented in pcb/README.md.
2026-11-01 chore: rename right_tb to right, drop plate PCBs, read plates from DXF
    The plates are ordered from production/plate/*.dxf, so their KiCad projects and pcb/ec/right go. The case scripts read the plate outlines from those DXFs.
2026-11-01 chore(pcb): mx_right routing from the KiCad save of 2026-11-01
2026-11-01 chore: license under MIT, move the GPL parts to the roBa fork
    The sensor board and the trackball case are GPL-3.0 and now live in Diwamoto/roBa (branch sage60); gerber.yml builds the board from there.
    J1 uses KiCad stock parts instead of roBa's, and the XIAO nRF52840 Plus footprint and symbol are drawn for this repo (pcb/modules) instead of Seeed's CC BY-SA ones. Copper, drills and the board outline are unchanged.
2026-11-01 chore(case): pin Python dependencies with hashes
    case/ had no requirements file and an unpinned venv. Direct dependencies
    are now listed in requirements.in and compiled with hashes, at the
    versions the current venv runs. ezdxf and trimesh are dropped: nothing
    imports them.
    matplotlib only draws the *_geo.png debug images, so it moves to
    requirements-debug.txt and make_left.py / make_right.py skip the image
    when it is missing. Setup needs Python 3.14, as 3.15 has no wheels for the
    pinned shapely and manifold3d.
    The four *_spec.json files come out byte-identical from the new venvs.
2026-11-01 chore(pcb): mx_right SCLK cleanup and symmetric J1 tongue
    Remove the SCLK 45-degree folds and dead ends, fix the acute angles and
    overlaps on COL4 / Net-(D28-A) / ROW4, and add 13 GND vias near the sensor
    wiring. Redraw the J1 tongue symmetric about J1's axis, inside the old
    outline, with no signal vias on it.
2026-11-02 feat(case): publish the gallery site on GitHub Pages
    The page fetches the GPL-3.0 trackball case from the roBa fork instead of
    carrying a copy, so this repository stays MIT.
2026-11-07 chore(case): build every variant in one Fusion document
    Fusion personal allows 10 editable documents and stage0 had filled them
    with duplicates: it only looked at open documents, so a closed one was
    saved again. Use sage60_case for left/right and MX/low-profile, and reopen
    it from the cloud when it is closed.
2026-11-08 fix(case): exact tangent joins on the outline, no wedge at the lowered front
    The fitted outlines kept few-degree kinks where a line meets an arc, and
    Fusion's R1 top fillet failed on them on the right side
    (ASM_BL_MITRE_NEAR_TANGENT). tangent_joins turns each line-arc-line
    corner into the exact fillet of its two lines (lines keep their
    direction, other sketches share them) and merges lines under 1 deg.
    TB_FRONT_LOW ran along the thumb keys into the wall at an acute angle;
    it now stops TB_FRONT_LOW_GAP short of the wall and leaves square to it.
2026-11-08 fix(firmware): trackball SPI at 1 MHz and pinned ZMK revisions
    The PMW3610 sits on ~18 cm of trace through J1, so run its SPI at half the
    sensor's maximum. Pin zmk and the pmw3610 driver to the commits the build
    was tested on, and point the overlay header at the current PCB path.
2026-11-08 feat(case): R1 top fillet, tent magnets, slide switch reference, refreshed prints
    - Top case: R1 fillet round the top outer edge instead of the 0.5
    chamfer; the right side fillets it before stage4's cuts and leaves the
    lowered front sharp (an R there ran under its step, a CNC undercut).
    - MX desk side: four phi6x3 magnets (TENT_MAG) for a tent wedge and for
    stacking the halves back to back; feet 1 mm or thinner are let in flush.
    tent_3mf.py writes the magnetic tent wedges.
    - Slide switch ISH-1260 as a reference body (SW_REF) in the interference
    check; its opening sits 1 mm toward -y and the scoop is centred on it.
    - Trackball pocket: close the 0.02 skin it left along the cavity wal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
2026-11-09 feat(site): wheel and pinch zoom in the viewer
2026-11-09 feat(site): pan in the viewer with right/shift-drag or two fingers
2026-11-10 feat(firmware): adjust layer keymap and rotated trackball
    Port the old zmk-config layers (Base/Lower/Raise) to the 58-key layout and
    add an Adjust layer (Lower+Raise) with BT select and studio_unlock. Keep the
    trackball clicks on Raise.
    Trackball: invert Y and rotate motion 15 degrees on the right half via a
    small local input device (config/rotate), so a sideways roll no longer
    drifts vertically. Tune with `angle` in sage60_right.overlay.
2026-11-10 feat(firmware): tune trackball rotation over BLE from a web page
    Move the rotate processor to the central so a bonded host can read and
    write its angle, per-axis angle, speed and wake threshold through a GATT
    characteristic; values persist in settings. case/site/tune.html drives
    it via Web Bluetooth. Also carries the pending wake-threshold, scroll
    invert and 500 ms temp-layer idle tweaks.
2026-11-10 feat(case): case foam DXFs for ordering (PCB underside and plate-PCB)
    case/foam_dxf.py -> production/case_foam/:
    - sage60_{left,right}_foam.dxf: fills PCB underside -> floor (4.4 mm) and
    touches the PCB; MX hot-swap sockets, diodes, battery/JST, MCU part and
    the trackball pocket/J1 tongue are cut out (Artair-X style)
    - sage60_{left,right}_plate_foam.dxf: between plate and PCB (3.8 mm gap),
    switch holes 14.5, MCU part and J1 cut out
    - foam_preview.png
2026-11-10 feat(firmware): tune trackball over USB serial instead of BLE
    Chrome on macOS doesn't list a keyboard already connected over Bluetooth,
    so the BLE tuning service was unusable. Expose the same settings on a
    second CDC ACM port (separate from ZMK Studio's) with a get/set line
    protocol, and switch tune.html to Web Serial.
2026-11-12 feat(firmware): gesture key for Mission Control/Esc, scroll speed tunable from tune page
